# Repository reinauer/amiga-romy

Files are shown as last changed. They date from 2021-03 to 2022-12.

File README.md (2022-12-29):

# Amiga Romy

ROMY is a small add-on PCB that enables Amiga 3000 / 4000 computers to use 1MB (or larger) Kickstart chips.

This project aims at iterating and improving the existing Romy designs.

# Software

Look in the [`software`](software/) directory for a bunch of scripts to create a nice 1MB ROM
image for you.

There's also a small program to create parametrized PLCC plug footprints for
KiCAD.

# Logic

The [`logic`](logic/) directory contains the contents for the GAL 22V10. If you want to
build a ROMY yourself, you will need to program this before soldering your GAL
down.

# Hardware

In the [`hardware`](hardware/) directory you will find the kicad schematics and PCB for the
latest versions of ROMY:

## Amiga 4000 Romy

This version was the first one I made. It fits snugly on top of a soldered-down
Fat Gary. The GAL is a PLCC-28 ATF22V10C type. This design is the most similar
to the original Romy.

<p float="left">
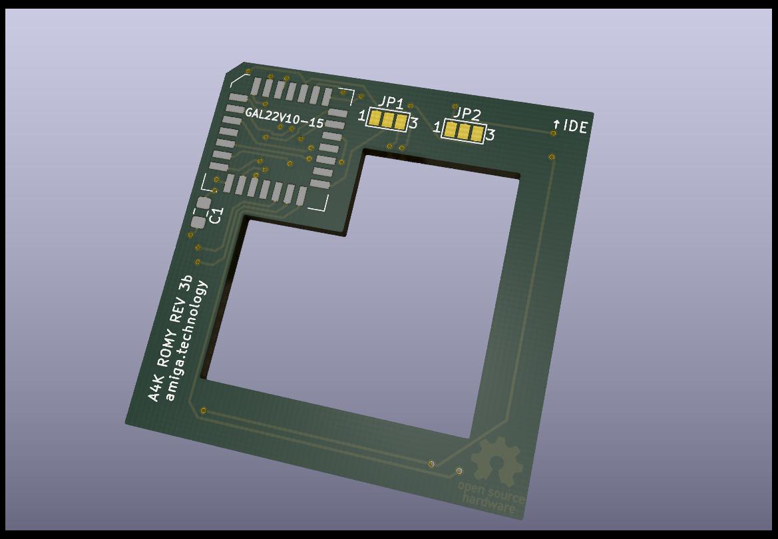
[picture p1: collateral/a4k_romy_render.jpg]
ROMY rendered

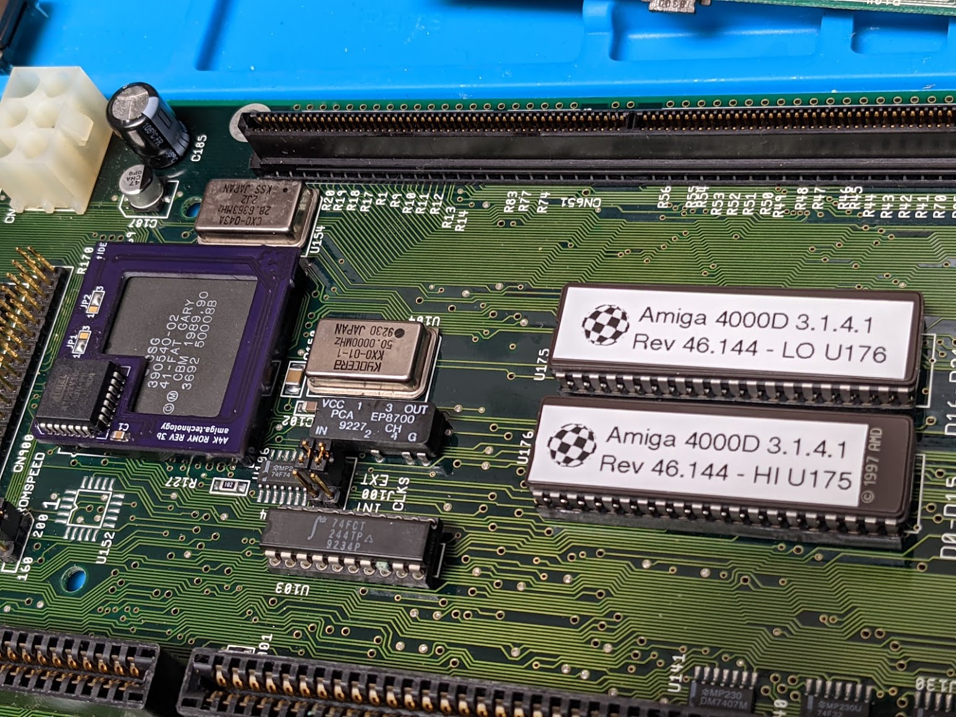
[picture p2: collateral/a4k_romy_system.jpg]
ROMY in the system

</p>

## Amiga 3000 Romy

This version is a revamp of the A3000 Romy. On the A3000 Fat Gary is socketed
using a through-hole PLCC-84 socket. Previous designs have required to unsolder
the socket, and solder a PCB between a socket and the mainboard, in some
variants adding a capacitor on the bottom of the mainboard.

This new design uses a PLCC-28 ATF22V10C GAL instead of the DIP version on
older Amiga 3000 designs. This is convenient because it lets you exchange GALs
between the A3000 and A4000 version.

To prevent having to solder on the A3000 board, I am using PLCC plugs (such as
the APW9328 from adapt-plus.com).

<p float="left">
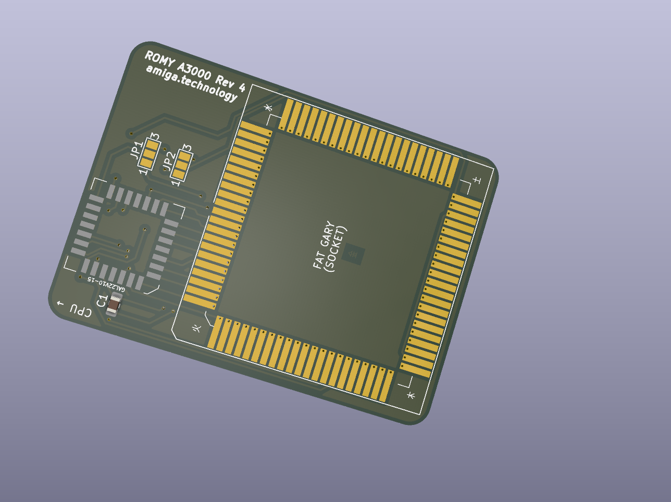
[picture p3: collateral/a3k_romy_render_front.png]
ROMY rendered

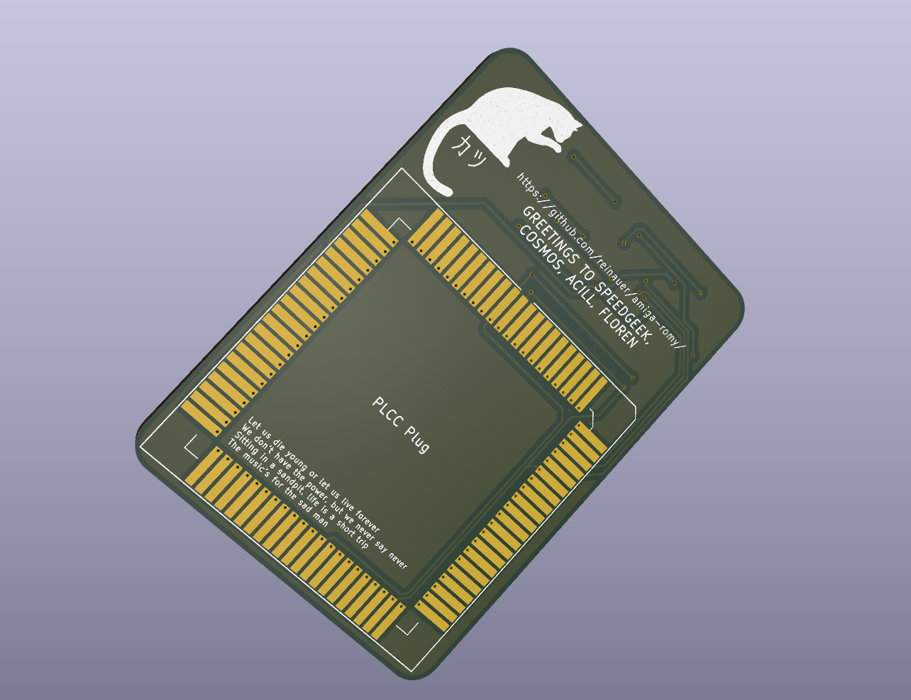
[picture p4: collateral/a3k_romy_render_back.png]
ROMY rendered (back)

</p>

## Ultimate Romy

Now this gets exciting. PLCC parts are annoying to solder and fairly big. So I
skipped DIP and SOIC and went straight to the TSOP version of the ATF22V10C.
The small footprint of this part allows to create a single board for Amiga 3000
and Amiga 4000 machines.

<p float="left">
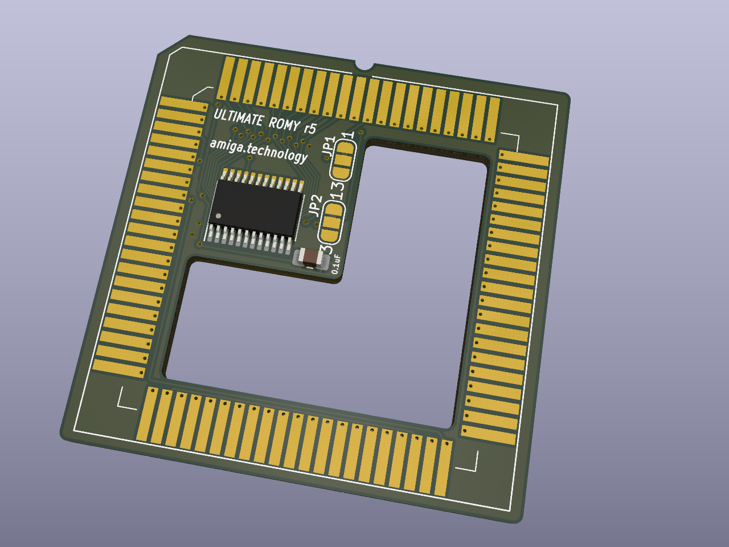
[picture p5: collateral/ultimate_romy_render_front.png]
ROMY rendered

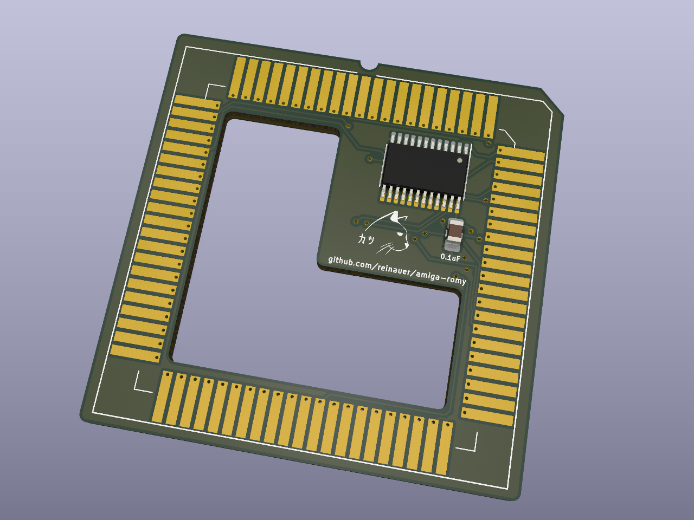
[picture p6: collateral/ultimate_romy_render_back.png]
ROMY rendered (back)

</p>

* If you want to build an A4000 Romy with this design, put a PLCC84 socket on the
back of the PCB, and a capacitor and GAL on the front.
* To build the A3000 version, instead solder a PLCC-84 socket on the front of
the PCB, and solder the cap and GAL on the bottom. Then solder the PLCC plug
over the components.

This design is barely wider than Fat Gary itself and adds the same
functionality as the other ROMYs with minimal impact.

# ROM Extender

<p float="left">
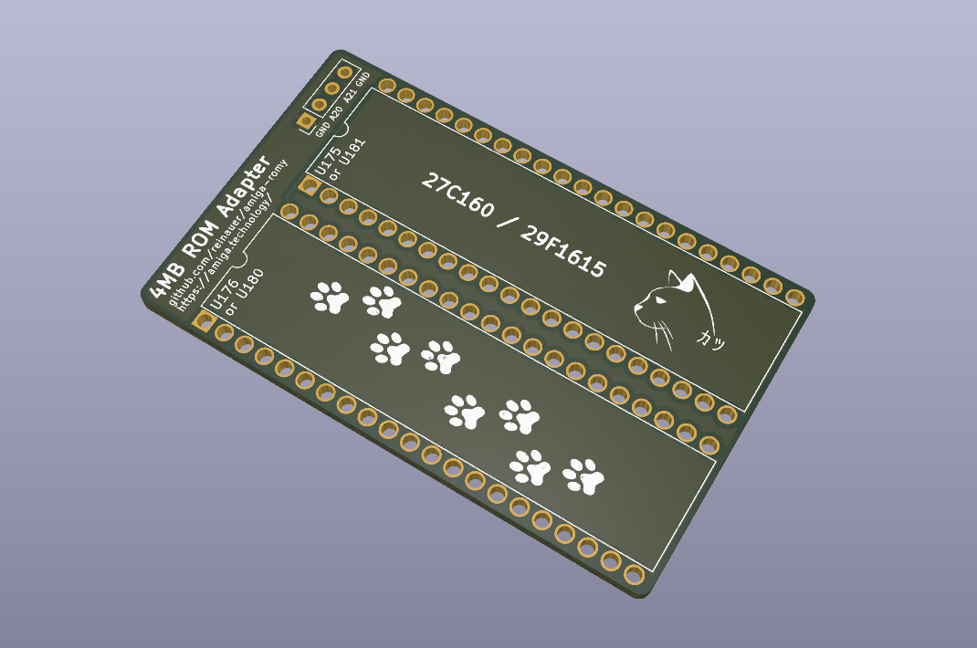
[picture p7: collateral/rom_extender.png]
ROMY 4MB ROM Extender

</p>

The ROM Extender allows the use of 4MB ROM space in an A3000/4000 with the
Ultimate ROMY r6 or newer versions of the A3000 ROMY. You need to connect the
additional address pins between the extender and your ROMY.

When assembling, make sure to optimize for height of the adapter as your
accelerator might have trouble fitting on the A4000.

# Credits

Romy has been developed in the past by speedgeek and Cosmos. Anton Gale kept
the designs alive on OSHPark. Thanks to John Floren for an amazing Amiga 3000,
and to Acill for patiently teaching soldering skills to firmware engineers like
me and for building an awesome community.

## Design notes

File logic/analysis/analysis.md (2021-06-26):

# Prerequisites

* Get OpalJr: wget http://www.brouhaha.com/~eric/retrocomputing/mmi/palasm/opaljr21.zip
* Install galette: https://github.com/simon-frankau/galette

# Get source files

* Use dosbox or dosemu with jed2eqn.
* See script.bat for an automated script

# Conver pin names
* run rename_pins.sh to rename the pins according to the schematics
```
  for f in *.EQN; do
    ./rename_pins.sh $f > ${f%.EQN}.pld
  done
```

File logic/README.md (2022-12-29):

# Logic Files

## Quick Start

The source code and self-compiled files are currently experimental. If you want
a known stable ROMY logic. please refer to the two files

 * RomyRev10.zip
 * RomyRev11.zip

## Overview

The jedec/ directory contains the logic files compiled from the source file in
source/.

There are two different revisions of ROMY:

* Revision 10 is the recommended one for A3000 and A4000D.
* Revision 11 might fix issues with the NCR 710 on A4000T

There are also different versions for 1MB and 4MB ROMYs.

## Building

make will compile all 4 combinations of ROMY logic. You will need
WinCUPL installed under wine.

Help / patches / improvements wanted.

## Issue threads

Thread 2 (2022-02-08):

Cannot make 2mb or 4mb kickstart images

MadMungo, 2022-02-08:
Stephan,

I can successfully make 1MB rom files but as soon as I try to make 2MB or 4MB rom files it errors out with the following

`madmungo@pop-os:~/Amig_Romy$ make kickstart TARGETS="A4000T" SIZES="4mb" VERSION="47.96"
Checking the programs required for the build are installed...
ROMY 1MB/2MB/4MB Kickstart patcher

Fasten your seatbelts and hold your breath (no, better don't!)

Gathering all files... Looking for Hyperion files
  * Can not find /home/madmungo/Downloads/AmigaOS-3.1.4-A3000.zip
  * Can not find /home/madmungo/Downloads/AmigaOS-3.1.4-A4000.zip
  * Can not find /home/madmungo/Downloads/AmigaOS-3.1.4-A4000T.zip
  * Can not find /home/madmungo/Downloads/AmigaOS-3.1.4.1-Update.zip
  * AmigaOS3.2CD.iso cached.
  * Can not find /home/madmungo/Downloads/kick_3.1.4.1.zip
  * Can not find /home/madmungo/Downloads/Update3.2.1.lha
Looking for add-on modules
  * arp40.2.lha cached.
  * vasm.tar.gz cached.
  * rnc_propack_source.zip cached.
  * hrtmon238.lha cached.
  * HRTModule236.lha cached.
  * pfs3aio.lha cached.
  * SFS.lha cached.
Looking for TF1260 drivers
  * ehide.tar.gz cached.
done
 * AmigaOS 3.1.4 A1200 files not found, skipping
 * AmigaOS 3.1.4 A3000 files not found, skipping
 * AmigaOS 3.1.4 A4000 files not found, skipping
 * AmigaOS 3.1.4 A4000T files not found, skipping
 * Unzipping AmigaOS 3.1.4.1 Update ...unzip:  cannot find or open /home/madmungo/Amig_Romy/archives/AmigaOS-3.1.4.1-Update.zip, /home/madmungo/Amig_Romy/archives/AmigaOS-3.1.4.1-Update.zip.zip or /home/madmungo/Amig_Romy/archives/AmigaOS-3.1.4.1-Update.zip.ZIP.
 ok
   * Unpacking * ... ok
 * Unpacking AmigaOS 3.2 ...[sudo] password for madmungo:
Need root access
   * Unpacking diskdoctor ... ok
   * Unpacking install3.2 ... ok
 * Unpacking Arp 40.2 ok
 * Unzipping hrtmodule238 ... ok
 * Unpacking vasm ... ok
 * Unpacking rnc_propack_source ... ok
 * Unpacking PFS3AIO ok
 * Unpacking SmartFileSystem ok
 * Unpacking TF1260 ehide.device ok
Compiling vasm... ok.
Compiling rnc_propack_source... ok.
Compressing hrtmon data... ok.
Compiling HRTmodule 2.38 (16.02.2021)... ok.
Processing Kickstart 47.96 for A4000T (4mb)
Header 11144ef9 512
make: *** [Makefile:31: kickstart] Error 1
`
I also cannot create any other size rom for any other target for any version after successfully  creating a 1MB rom it errors with
make: *** [Makefile:31: kickstart] Error 2. This also happens if I try to make a rom after a reboot of the machine.

reinauer, 2022-02-09:
Yeah, you need to install the latest git revision of amitools. Unfortunately Christian has not released a new version of amitools in the last year or so. that would include my fixes.

MadMungo, 2022-02-09:
Ah OK.

So I am not a linux user, never had to compile stuff before. Are there
instructions on his github page for doing that? & do they include your
fixes?

Phillip

On Wed, 9 Feb 2022, 12:48 pm Stefan Reinauer, ***@***.***>
wrote:

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

reinauer, 2022-02-09:
[According to the author,](https://github.com/cnvogelg/amitools/issues/165) you can install it via
```
pip install -U git+https://github.com/cnvogelg/amitools.git
```

MadMungo, 2022-02-10:
Ok, thanks.

Yes that works for me. Can create all 3 sizes of rom now.

On Thu, 10 Feb 2022, 5:30 am Stefan Reinauer, ***@***.***>
wrote:

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

Closed 2022-02-12.

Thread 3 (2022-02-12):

Cannot make kickstart images for a1200

mikketeus, 2022-02-12:
Hi

I have a TF1260 and would very much like to autoboot from a faster IDE.
I can build A4000 images without any trouble, but not a1200 for some reason?=

make kickstart TARGETS="A1200" VERSION=47.96 SIZES="1mb"
Checking the programs required for the build are installed...
ROMY 1MB/2MB/4MB Kickstart patcher

Fasten your seatbelts and hold your breath (no, better don't!)

Gathering all files... Looking for Hyperion files
  * Can not find /root/Downloads/AmigaOS-3.1.4-A3000.zip
  * Can not find /root/Downloads/AmigaOS-3.1.4-A4000.zip
  * Can not find /root/Downloads/AmigaOS-3.1.4-A4000T.zip
  * Can not find /root/Downloads/AmigaOS-3.1.4.1-Update.zip
  * AmigaOS3.2CD.iso cached.
  * Can not find /root/Downloads/kick_3.1.4.1.zip
  * Can not find /root/Downloads/Update3.2.1.lha
Looking for add-on modules
  * arp40.2.lha cached.
  * vasm.tar.gz cached.
  * rnc_propack_source.zip cached.
  * hrtmon238.lha cached.
  * HRTModule236.lha cached.
  * pfs3aio.lha cached.
  * SFS.lha cached.
Looking for TF1260 drivers
  * ehide.tar.gz cached.
done
 * AmigaOS 3.1.4 A1200 files not found, skipping
 * AmigaOS 3.1.4 A3000 files not found, skipping
 * AmigaOS 3.1.4 A4000 files not found, skipping
 * AmigaOS 3.1.4 A4000T files not found, skipping
 * Unzipping AmigaOS 3.1.4.1 Update ...unzip:  cannot find or open ~/dev/Github/amiga-romy/software/archives/AmigaOS-3.1.4.1-Update.zip,~/dev/Github/amiga-romy/software/archives/AmigaOS-3.1.4.1-Update.zip.zip or ~/dev/Github/amiga-romy/software/archives/AmigaOS-3.1.4.1-Update.zip.ZIP.
 ok
   * Unpacking * ... ok
 * Unpacking AmigaOS 3.2 ...Need root access
   * Unpacking diskdoctor ... ok
   * Unpacking install3.2 ... ok
 * Unpacking Arp 40.2 ok
 * Unzipping hrtmodule238 ... ok
 * Unpacking vasm ... ok
 * Unpacking rnc_propack_source ... ok
 * Unpacking PFS3AIO ok
 * Unpacking SmartFileSystem ok
 * Unpacking TF1260 ehide.device ok
Compiling vasm... ok.
Compiling rnc_propack_source... ok.
Compressing hrtmon data... ok.
Compiling HRTmodule 2.38 (16.02.2021)... ok.
Processing Kickstart 47.96 for A1200 (1mb)
Header 11144ef9 512
make: *** [Makefile:31: kickstart] Error 2

mikketeus, 2022-02-12:
Nevermind, I did some chown's and used my normal user and it worked.

reinauer, 2022-02-12:
Check out this one as well for installing the latest version of amitools
needed for larger rom images and some other features

https://github.com/reinauer/amiga-romy/issues/2#issuecomment-1034068938

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

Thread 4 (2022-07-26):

Assembly error for A1200

JV-Soft, 2022-07-26:
I updated all packages .
Kickstart patch for A4000 and A4000T is made normally only with ROOT, Kickstart patch for A500, A1200, A3000 is an error, it doesn’t matter if there is a ROOT or not

For A4000 -

am@jam-VirtualBox:~/amiga-romy/software$ sudo make kickstart TARGETS="A4000" VERSION=47.102 SIZES="1mb"
Checking the programs required for the build are installed...
ROMY 1MB/2MB/4MB Kickstart patcher

Fasten your seatbelts and hold your breath (no, better don't!)

Processing Kickstart 47.102 for A4000 (1mb)
Header 11144ef9 512
Header 11144ef9 512
Header 11144ef9 512
Success! Now write build/47.102/kick.a4000.47.102.1mb.LO.bin and build/47.102/kick.a4000.47.102.1mb.HI.bin to two 27C400 chips (A4000).

--------------------------------------------------------------------
For A1200 -

jam@jam-VirtualBox:~/amiga-romy/software$ sudo make kickstart TARGETS="A1200" VERSION=47.96 SIZES="1mb"
[sudo] password for jam:
Checking the programs required for the build are installed...
ROMY 1MB/2MB/4MB Kickstart patcher

Fasten your seatbelts and hold your breath (no, better don't!)

Processing Kickstart 47.96 for A1200 (1mb)
Header 11144ef9 512
make: *** [Makefile:31: kickstart] Error 2

------------------------------------------------------------------------------------

After a clean install -

jam@jam-VirtualBox:~/amiga-romy/software$ sudo make kickstart TARGETS="A1200" VERSION=47.96 SIZES="1mb"
Checking the programs required for the build are installed...
ROMY 1MB/2MB/4MB Kickstart patcher

Fasten your seatbelts and hold your breath (no, better don't!)

Gathering all files... Looking for Hyperion files
  * Can not find /root/Downloads/AmigaOS-3.1.4-A3000.zip
  * Can not find /root/Downloads/AmigaOS-3.1.4-A4000.zip
  * Can not find /root/Downloads/AmigaOS-3.1.4-A4000T.zip
  * Can not find /root/Downloads/AmigaOS-3.1.4.1-Update.zip
  * AmigaOS3.2CD.iso cached.
  * Can not find /root/Downloads/kick_3.1.4.1.zip
  * Update3.2.1.lha cached.
Looking for add-on modules
  * arp40.2.lha cached.
  * vasm.tar.gz cached.
  * rnc_propack_source.zip cached.
  * hrtmon238.lha cached.
  * HRTModule236.lha cached.
  * pfs3aio.lha cached.
  * SFS.lha cached.
Looking for TF1260 drivers
  * ehide.tar.gz cached.
done
 * AmigaOS 3.1.4 A1200 files not found, skipping
 * AmigaOS 3.1.4 A3000 files not found, skipping
 * AmigaOS 3.1.4 A4000 files not found, skipping
 * AmigaOS 3.1.4 A4000T files not found, skipping
 * Unzipping AmigaOS 3.1.4.1 Update ...unzip:  cannot find or open /home/jam/amiga-romy/software/archives/AmigaOS-3.1.4.1-Update.zip, /home/jam/amiga-romy/software/archives/AmigaOS-3.1.4.1-Update.zip.zip or /home/jam/amiga-romy/software/archives/AmigaOS-3.1.4.1-Update.zip.ZIP.
 ok
   * Unpacking * ... ok
 * Unpacking AmigaOS 3.2 ...Need root access
   * Unpacking diskdoctor ... ok
   * Unpacking install3.2 ... ok
 * Unpacking AmigaOS 3.2.1 Update ... ok
   * Unpacking DiskDoctor ... ok
   * Unpacking Update3.2.1 ... ok
 * Unpacking Arp 40.2 ok
 * Unzipping hrtmodule238 ... ok
 * Unpacking vasm ... ok
 * Unpacking rnc_propack_source ... ok
 * Unpacking PFS3AIO ok
 * Unpacking SmartFileSystem ok
 * Unpacking TF1260 ehide.device ok
Compiling vasm... cached.
Compiling rnc_propack_source... cached.
Compressing hrtmon data... cached.
Compiling HRTmodule 2.38 (16.02.2021)... cached.
Processing Kickstart 47.96 for A1200 (1mb)
Header 11144ef9 512
make: *** [Makefile:31: kickstart] Error 2

JV-Soft, 2022-07-26:
I also wanted to say that after the error, only one file is created in the build / 47.96 folder, this is kick.a1200.47.96-512kb
I checked it, it's a working kickstart 47.96

JV-Soft, 2022-07-26:
Updated amitools as you recommended, did not help

jam@jam-VirtualBox:~/amiga-romy/software$ make kickstart TARGETS="A1200" VERSION=47.96 SIZES="1mb"
Checking the programs required for the build are installed...
ROMY 1MB/2MB/4MB Kickstart patcher

Fasten your seatbelts and hold your breath (no, better don't!)

Processing Kickstart 47.96 for A1200 (1mb)
2022-07-26 23:44:18,628  ERROR       root        IO Error: [Errno 13] Permission denied: 'ArpLib40.2/arp.library'
make: *** [Makefile:31: kickstart] Error 1

With ROOT rights -

jam@jam-VirtualBox:~/amiga-romy/software$ sudo make kickstart TARGETS="A1200" VERSION=47.96 SIZES="1mb"
[sudo] password for jam:
Checking the programs required for the build are installed...
ROMY 1MB/2MB/4MB Kickstart patcher

Fasten your seatbelts and hold your breath (no, better don't!)

Processing Kickstart 47.96 for A1200 (1mb)
Header 11144ef9 512
make: *** [Makefile:31: kickstart] Error 2

JV-Soft, 2022-07-26:
And again, the A4000 and A4000T are being made, but the rest are not -

jam@jam-VirtualBox:~/amiga-romy/software$ sudo make kickstart TARGETS="A4000" VERSION=47.96 SIZES="1mb"
Checking the programs required for the build are installed...
ROMY 1MB/2MB/4MB Kickstart patcher

Fasten your seatbelts and hold your breath (no, better don't!)

Processing Kickstart 47.96 for A4000 (1mb)
Header 11144ef9 512
Header 11144ef9 512
Header 11144ef9 512
Success! Now write build/47.96/kick.a4000.47.96.1mb.LO.bin and build/47.96/kick.a4000.47.96.1mb.HI.bin to two 27C400 chips (A4000).

jam@jam-VirtualBox:~/amiga-romy/software$ sudo make kickstart TARGETS="A4000T" VERSION=47.96 SIZES="1mb"
Checking the programs required for the build are installed...
ROMY 1MB/2MB/4MB Kickstart patcher

Fasten your seatbelts and hold your breath (no, better don't!)

Processing Kickstart 47.96 for A4000T (1mb)
Header 11144ef9 512
Header 11144ef9 512
Header 11144ef9 512
Success! Now write build/47.96/kick.a4000t.47.96.1mb.LO.bin and build/47.96/kick.a4000t.47.96.1mb.HI.bin to two 27C400 chips (A4000T).

jam@jam-VirtualBox:~/amiga-romy/software$ sudo make kickstart TARGETS="A3000" VERSION=47.96 SIZES="1mb"
Checking the programs required for the build are installed...
ROMY 1MB/2MB/4MB Kickstart patcher

Fasten your seatbelts and hold your breath (no, better don't!)

Processing Kickstart 47.96 for A3000 (1mb)
Header 11144ef9 512
make: *** [Makefile:31: kickstart] Error 2
jam@jam-VirtualBox:~/amiga-romy/software$ sudo make kickstart TARGETS="A500" VERSION=47.96 SIZES="1mb"
Checking the programs required for the build are installed...
ROMY 1MB/2MB/4MB Kickstart patcher

Fasten your seatbelts and hold your breath (no, better don't!)

Processing Kickstart 47.96 for A500 (1mb)
Header 11144ef9 512
make: *** [Makefile:31: kickstart] Error 2
jam@jam-VirtualBox:~/amiga-romy/software$ sudo make kickstart TARGETS="A1200" VERSION=47.96 SIZES="1mb"
Checking the programs required for the build are installed...
ROMY 1MB/2MB/4MB Kickstart patcher

Fasten your seatbelts and hold your breath (no, better don't!)

Processing Kickstart 47.96 for A1200 (1mb)
Header 11144ef9 512
make: *** [Makefile:31: kickstart] Error 2

reinauer, 2022-09-08:
Your first comment has files left over from running as root. You need to clean them out. The second post is once again using the wrong version of amitools. (probably because the new version is installed for the user but you are running as root again).

JV-Soft, 2022-11-16:
Thank you very much for your work and support!

ср, 16 нояб. 2022 г. в 06:34, Stefan Reinauer ***@***.***>:

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

Closed 2022-11-16.

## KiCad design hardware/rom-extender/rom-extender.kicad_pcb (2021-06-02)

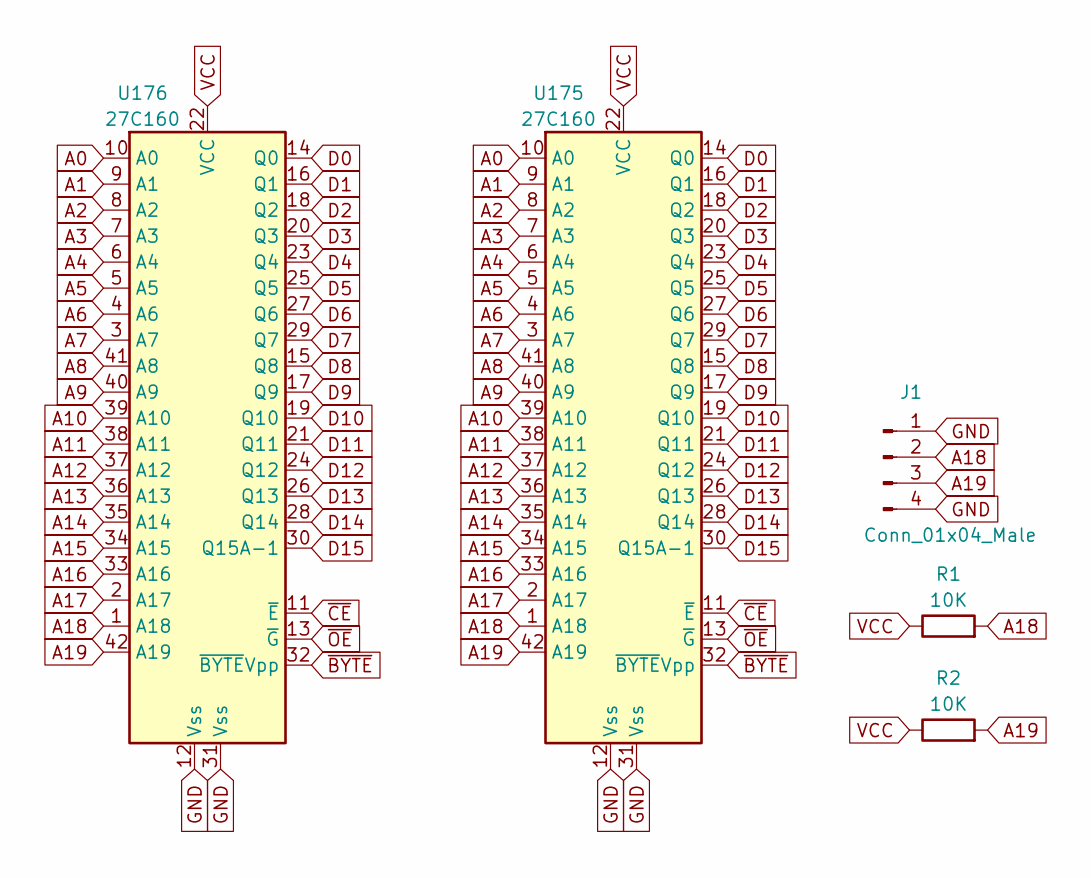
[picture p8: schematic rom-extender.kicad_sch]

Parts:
J1: Conn_01x04_Male; PinHeader_1x04_P2.54mm_Vertical
R1, R2: 10K; R_0805_2012Metric_Pad1.20x1.40mm_HandSolder
U175, U176: 27C160; DIP-42_W15.24mm

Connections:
A0: U175.10 (A0), U176.10 (A0)
A1: U175.9 (A1), U176.9 (A1)
A2: U175.8 (A2), U176.8 (A2)
A3: U175.7 (A3), U176.7 (A3)
A4: U175.6 (A4), U176.6 (A4)
A5: U175.5 (A5), U176.5 (A5)
A6: U175.4 (A6), U176.4 (A6)
A7: U175.3 (A7), U176.3 (A7)
A8: U175.41 (A8), U176.41 (A8)
A9: U175.40 (A9), U176.40 (A9)
A10: U175.39 (A10), U176.39 (A10)
A11: U175.38 (A11), U176.38 (A11)
A12: U175.37 (A12), U176.37 (A12)
A13: U175.36 (A13), U176.36 (A13)
A14: U175.35 (A14), U176.35 (A14)
A15: U175.34 (A15), U176.34 (A15)
A16: U175.33 (A16), U176.33 (A16)
A17: U175.2 (A17), U176.2 (A17)
A18: J1.2, R1.2, U175.1 (A18), U176.1 (A18)
A19: J1.3, R2.2, U175.42 (A19), U176.42 (A19)
D0: U175.14 (Q0), U176.14 (Q0)
D1: U175.16 (Q1), U176.16 (Q1)
D2: U175.18 (Q2), U176.18 (Q2)
D3: U175.20 (Q3), U176.20 (Q3)
D4: U175.23 (Q4), U176.23 (Q4)
D5: U175.25 (Q5), U176.25 (Q5)
D6: U175.27 (Q6), U176.27 (Q6)
D7: U175.29 (Q7), U176.29 (Q7)
D8: U175.15 (Q8), U176.15 (Q8)
D9: U175.17 (Q9), U176.17 (Q9)
D10: U175.19 (Q10), U176.19 (Q10)
D11: U175.21 (Q11), U176.21 (Q11)
D12: U175.24 (Q12), U176.24 (Q12)
D13: U175.26 (Q13), U176.26 (Q13)
D14: U175.28 (Q14), U176.28 (Q14)
D15: U175.30 (Q15A-1), U176.30 (Q15A-1)
GND: J1.1, J1.4, U175.12 (Vss), U175.31 (Vss), U176.12 (Vss), U176.31 (Vss)
VCC: R1.1, R2.1, U175.22 (VCC), U176.22 (VCC)
~BYTE: U175.32 (~BYTE~Vpp), U176.32 (~BYTE~Vpp)
~CE: U175.11 (~E), U176.11 (~E)
~OE: U175.13 (~G), U176.13 (~G)

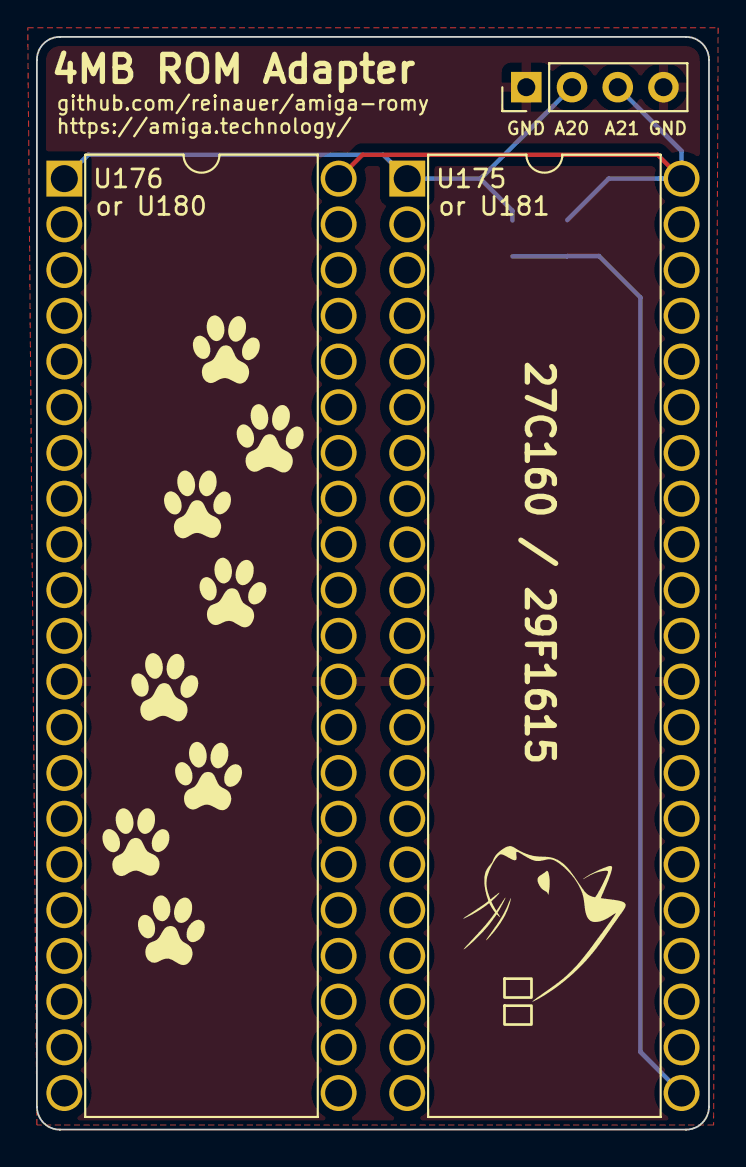
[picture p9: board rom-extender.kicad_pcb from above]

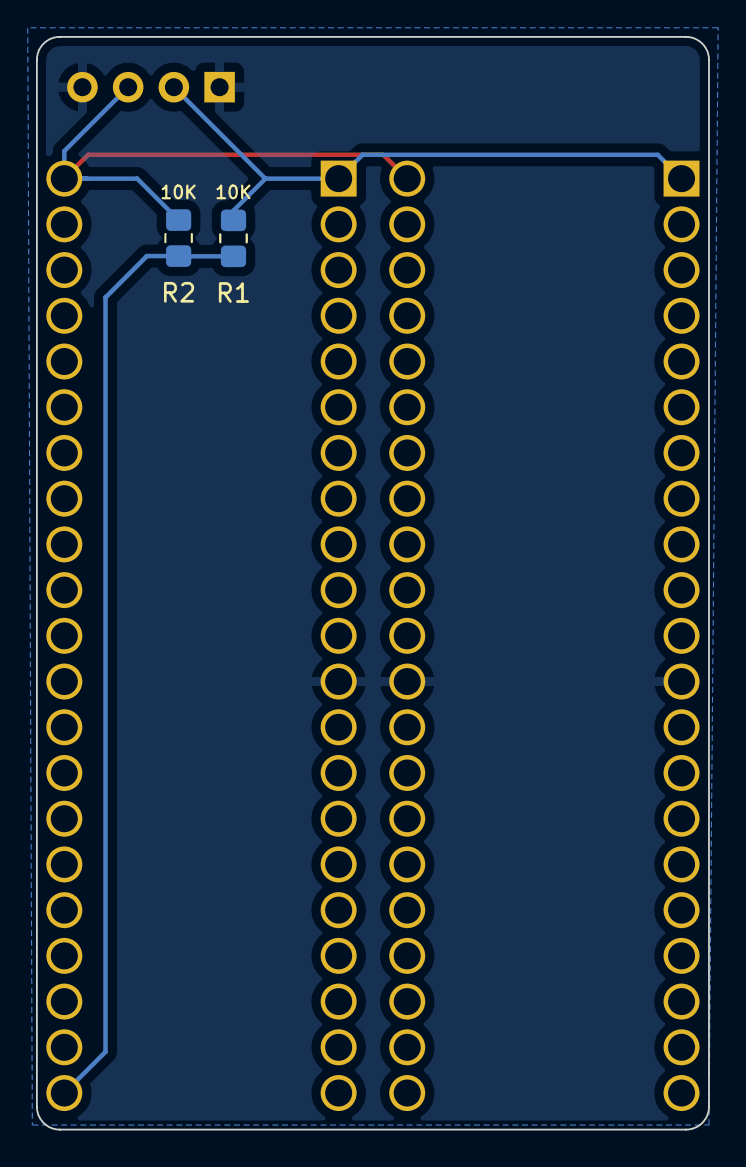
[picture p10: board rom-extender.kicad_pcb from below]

Board: 2 copper layers, 37.3 x 60.7 mm, 5 parts (2 on the bottom side), 41 nets.

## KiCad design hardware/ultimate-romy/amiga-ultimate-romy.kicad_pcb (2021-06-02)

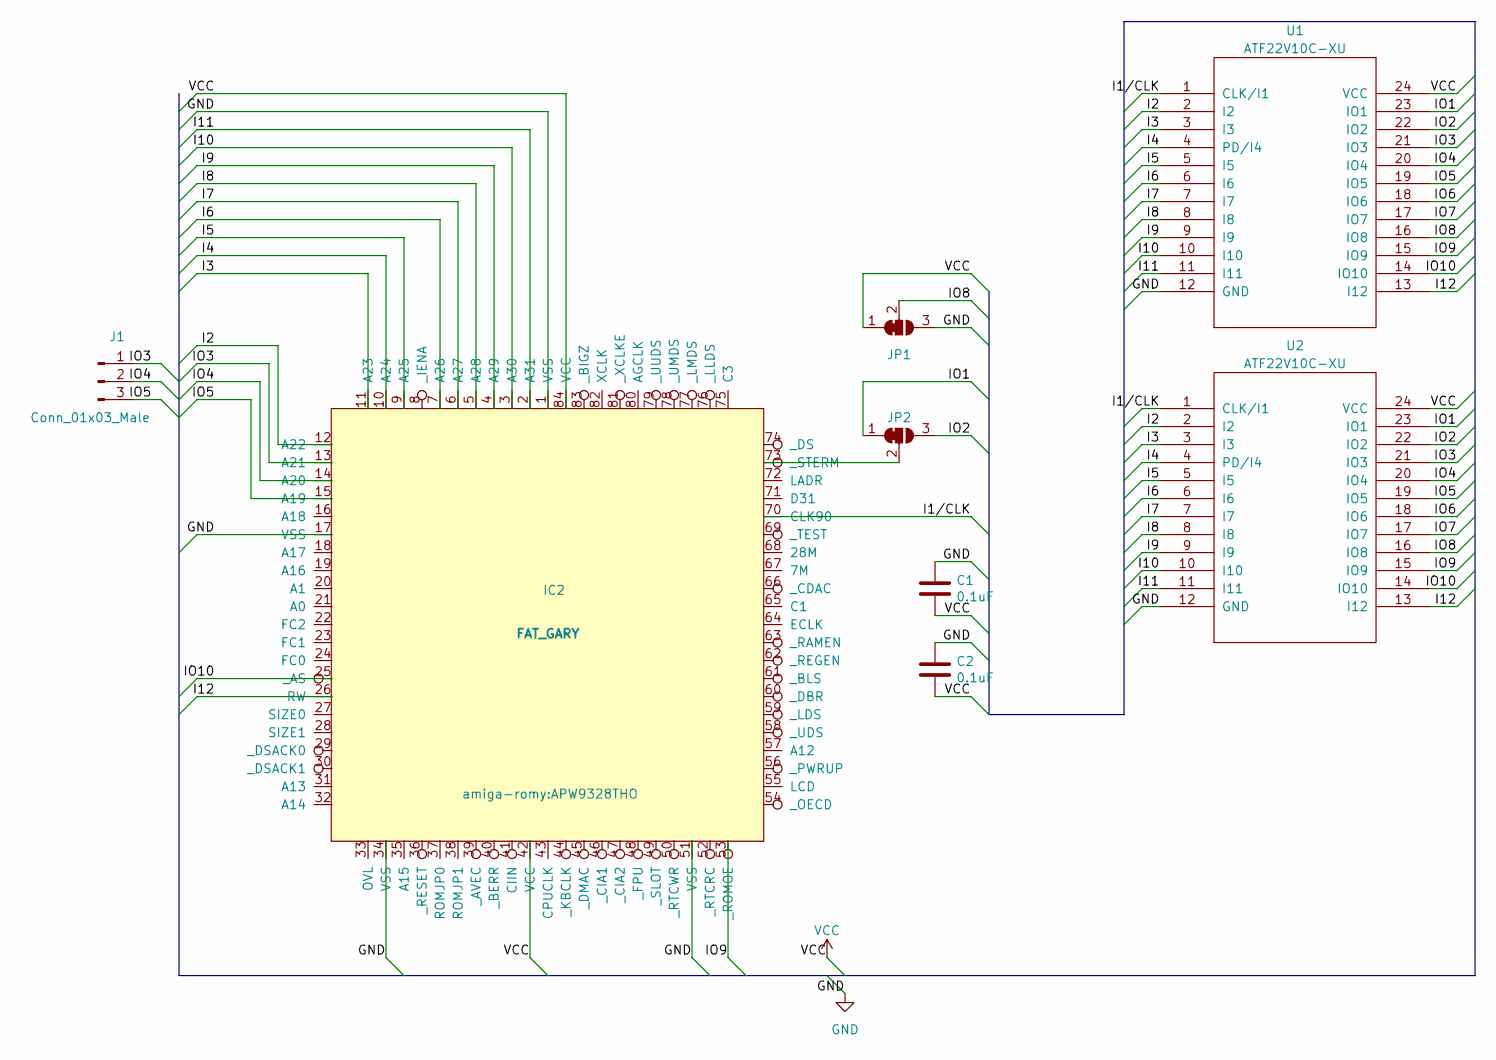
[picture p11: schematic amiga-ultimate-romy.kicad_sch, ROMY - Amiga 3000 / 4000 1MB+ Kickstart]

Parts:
C1, C2: 0.1uF; C_0805_2012Metric_Pad1.18x1.45mm_HandSolder
IC2: FAT_GARY; APW9328THO
J1: Conn_01x03_Male; PinHeader_1x03_P2.54mm_Vertical
JP1, JP2: SolderJumper_3_Bridged12; SolderJumper-3_P1.3mm_Bridged12_RoundedPad1.0x1.5mm_NumberL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
U1, U2: ATF22V10C-XU; asym_TSSOP-24_4.4x7.8mm_P0.65mm

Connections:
/I1/CLK: IC2.70 (CLK90), U1.1 (CLK/I1), U2.1 (CLK/I1)
/I2: IC2.12 (A22), U1.2 (I2), U2.2 (I2)
/I3: IC2.11 (A23), U1.3 (I3), U2.3 (I3)
/I4: IC2.10 (A24), U1.4 (PD/I4), U2.4 (PD/I4)
/I5: IC2.9 (A25), U1.5 (I5), U2.5 (I5)
/I6: IC2.7 (A26), U1.6 (I6), U2.6 (I6)
/I7: IC2.6 (A27), U1.7 (I7), U2.7 (I7)
/I8: IC2.5 (A28), U1.8 (I8), U2.8 (I8)
/I9: IC2.4 (A29), U1.9 (I9), U2.9 (I9)
/I10: IC2.3 (A30), U1.10 (I10), U2.10 (I10)
/I11: IC2.2 (A31), U1.11 (I11), U2.11 (I11)
/I12: IC2.26 (RW), U1.13 (I12), U2.13 (I12)
/IO1: JP2.1 (A), U1.23 (IO1), U2.23 (IO1)
/IO2: JP2.3 (B), U1.22 (IO2), U2.22 (IO2)
/IO3: IC2.13 (A21), J1.1, U1.21 (IO3), U2.21 (IO3)
/IO4: IC2.14 (A20), J1.2, U1.20 (IO4), U2.20 (IO4)
/IO5: IC2.15 (A19), J1.3, U1.19 (IO5), U2.19 (IO5)
/IO6: U1.18 (IO6), U2.18 (IO6)
/IO7: U1.17 (IO7), U2.17 (IO7)
/IO8: JP1.2 (C), U1.16 (IO8), U2.16 (IO8)
/IO9: IC2.53 (_ROMOE), U1.15 (IO9), U2.15 (IO9)
/IO10: IC2.25 (_AS), U1.14 (IO10), U2.14 (IO10)
GND: C1.1, C2.1, IC2.1 (VSS), IC2.17 (VSS), IC2.34 (VSS), IC2.51 (VSS), JP1.3 (B), U1.12 (GND), U2.12 (GND)
unnamed: IC2.73 (_STERM), JP2.2 (C)
VCC: C1.2, C2.2, IC2.42 (VCC), IC2.84 (VCC), JP1.1 (A), U1.24 (VCC), U2.24 (VCC)

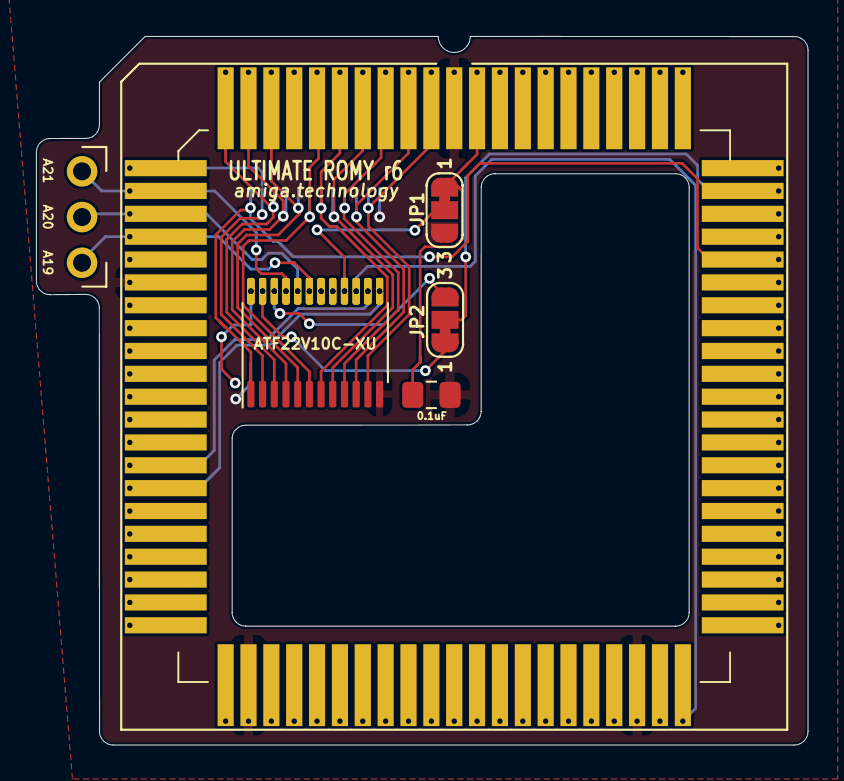
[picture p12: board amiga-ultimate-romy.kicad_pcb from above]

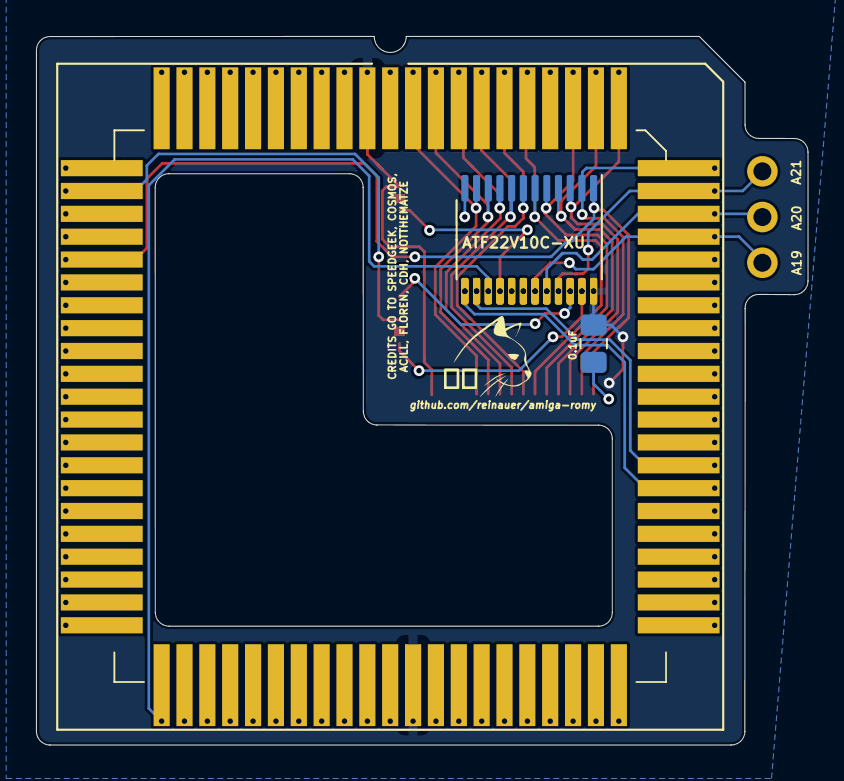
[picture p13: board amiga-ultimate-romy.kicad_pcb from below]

Board: 2 copper layers, 42.9 x 39.4 mm, 9 parts (3 on the bottom side), 25 nets.

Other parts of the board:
カツ: Katsu

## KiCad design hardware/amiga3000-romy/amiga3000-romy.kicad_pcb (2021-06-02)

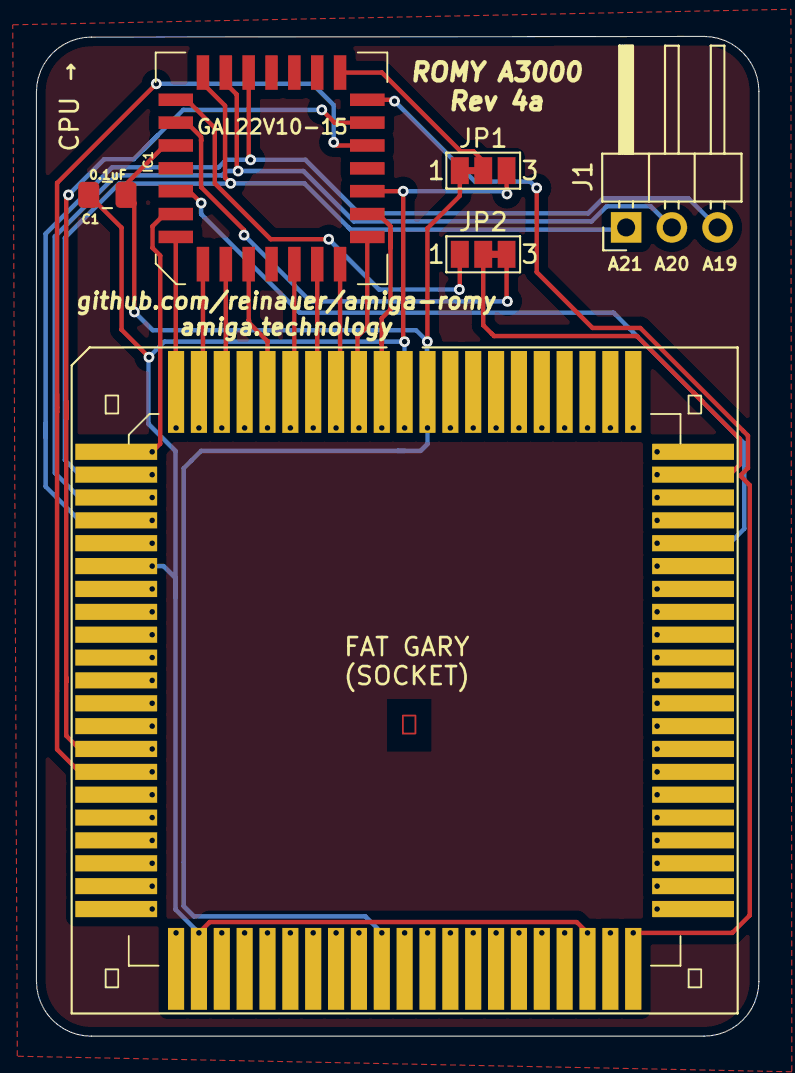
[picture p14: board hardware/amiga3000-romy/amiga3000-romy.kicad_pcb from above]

Board: 2 copper layers, 40.1 x 55.5 mm, 6 parts (1 on the bottom side), 23 nets.

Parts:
C1: 0.1uF; C_0805_2012Metric_Pad1.18x1.45mm_HandSolder
IC1: GAL22V10; PLCC-28
IC2: FAT_GARY; APW9328TH
J1: Conn_01x03_Male; PinHeader_1x03_P2.54mm_Horizontal
JP1: SolderJumper_3_Open; SolderJumper-3_P1.3mm_Closed_12_Pad1.0x1.5mm_NumberLabels
JP2: SolderJumper_3_Open; SolderJumper-3_P1.3mm_Closed_23_Pad1.0x1.5mm_NumberLabels

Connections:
unnamed: C1.1, IC1.14 (GND), IC2.1 (VSS), IC2.17 (VSS), IC2.34 (VSS), IC2.51 (VSS), JP1.3 (B)
unnamed: C1.2, IC1.28 (VCC), IC2.42 (VCC), IC2.84 (VCC), JP1.1 (A)
unnamed: IC1.2 (I1/CLK), IC2.70 (CLK90)
unnamed: IC1.3 (I2), IC2.12 (A22)
unnamed: IC1.4 (I3), IC2.11 (A23)
unnamed: IC1.5 (I4), IC2.10 (A24)
unnamed: IC1.6 (I5), IC2.9 (A25)
unnamed: IC1.7 (I6), IC2.7 (A26)
unnamed: IC1.9 (I7), IC2.6 (A27)
unnamed: IC1.10 (I8), IC2.5 (A28)
unnamed: IC1.11 (I9), IC2.4 (A29)
unnamed: IC1.12 (I10), IC2.3 (A30)
unnamed: IC1.13 (I11), IC2.2 (A31)
unnamed: IC1.16 (I12), IC2.26 (RW)
unnamed: IC1.17 (IO10), IC2.25 (_AS)
unnamed: IC1.18 (IO9), IC2.53 (_ROMOE)
unnamed: IC1.19 (IO8), JP1.2 (C)
unnamed: IC1.23 (IO5), IC2.15 (A19), J1.3
unnamed: IC1.24 (IO4), IC2.14 (A20), J1.2
unnamed: IC1.25 (IO3), IC2.13 (A21), J1.1
unnamed: IC1.26 (IO2), JP2.1 (A)
unnamed: IC1.27 (IO1), JP2.3 (B)
unnamed: IC2.73 (_STERM), JP2.2 (C)

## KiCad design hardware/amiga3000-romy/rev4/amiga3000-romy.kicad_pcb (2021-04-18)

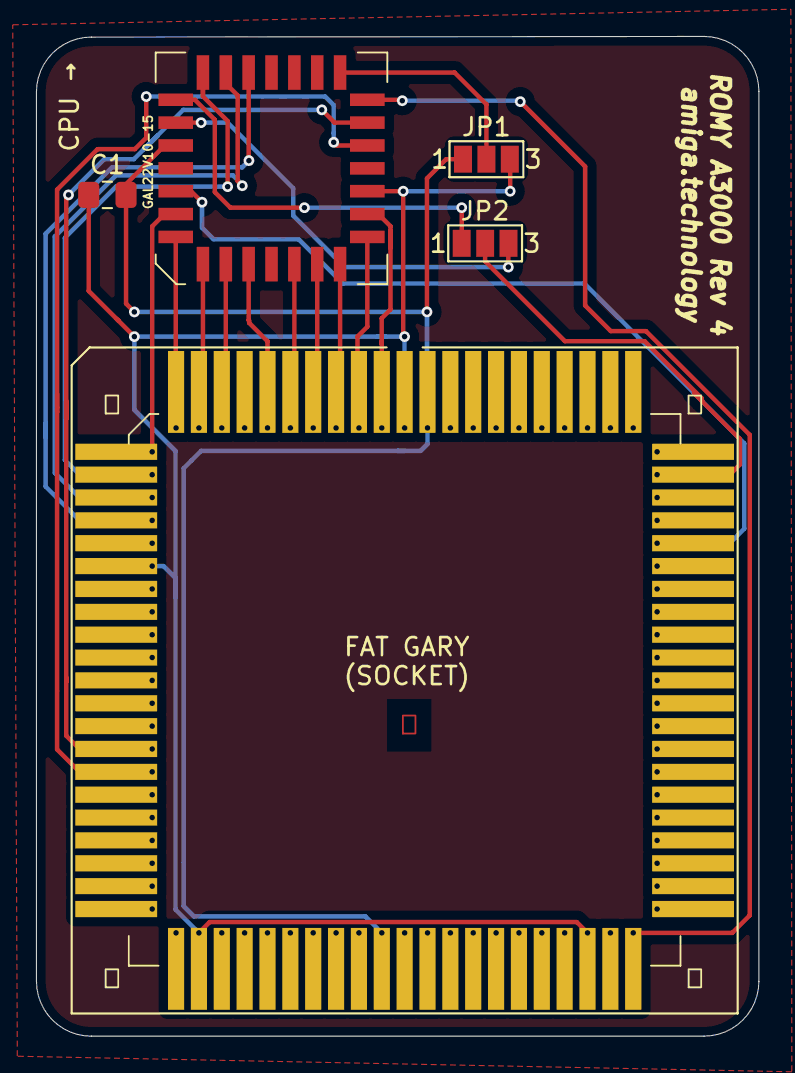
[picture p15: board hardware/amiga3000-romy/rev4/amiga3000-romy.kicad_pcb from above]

Board: 2 copper layers, 40.1 x 55.5 mm, 5 parts (1 on the bottom side), 23 nets.

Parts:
 : FAT_GARY; APW9328TH
C1: 0.1uF; C_0805_2012Metric_Pad1.18x1.45mm_HandSolder
GAL22V10-15: GAL22V10; PLCC-28
JP1, JP2: SolderJumper_3_Open; SolderJumper-3_P1.3mm_Open_Pad1.0x1.5mm_NumberLabels

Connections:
unnamed: .1 (VSS), .17 (VSS), .34 (VSS), .51 (VSS), C1.1, GAL22V10-15.14 (GND), JP1.3 (B)
unnamed: .42 (VCC), .84 (VCC), C1.2, GAL22V10-15.28 (VCC), JP1.1 (A)
unnamed: .70 (CLK90), GAL22V10-15.2 (I1/CLK)
unnamed: .12 (A22), GAL22V10-15.3 (I2)
unnamed: .11 (A23), GAL22V10-15.4 (I3)
unnamed: .10 (A24), GAL22V10-15.5 (I4)
unnamed: .9 (A25), GAL22V10-15.6 (I5)
unnamed: .7 (A26), GAL22V10-15.7 (I6)
unnamed: .6 (A27), GAL22V10-15.9 (I7)
unnamed: .5 (A28), GAL22V10-15.10 (I8)
unnamed: .4 (A29), GAL22V10-15.11 (I9)
unnamed: .3 (A30), GAL22V10-15.12 (I10)
unnamed: .2 (A31), GAL22V10-15.13 (I11)
unnamed: .26 (RW), GAL22V10-15.16 (I12)
unnamed: .25 (_AS), GAL22V10-15.17 (IO10)
unnamed: .53 (_ROMOE), GAL22V10-15.18 (IO9)
unnamed: GAL22V10-15.19 (IO8), JP1.2 (C)
unnamed: .15 (A19), GAL22V10-15.23 (IO5)
unnamed: .14 (A20), GAL22V10-15.24 (IO4)
unnamed: .13 (A21), GAL22V10-15.25 (IO3)
unnamed: GAL22V10-15.26 (IO2), JP2.1 (A)
unnamed: GAL22V10-15.27 (IO1), JP2.3 (B)
unnamed: .73 (_STERM), JP2.2 (C)

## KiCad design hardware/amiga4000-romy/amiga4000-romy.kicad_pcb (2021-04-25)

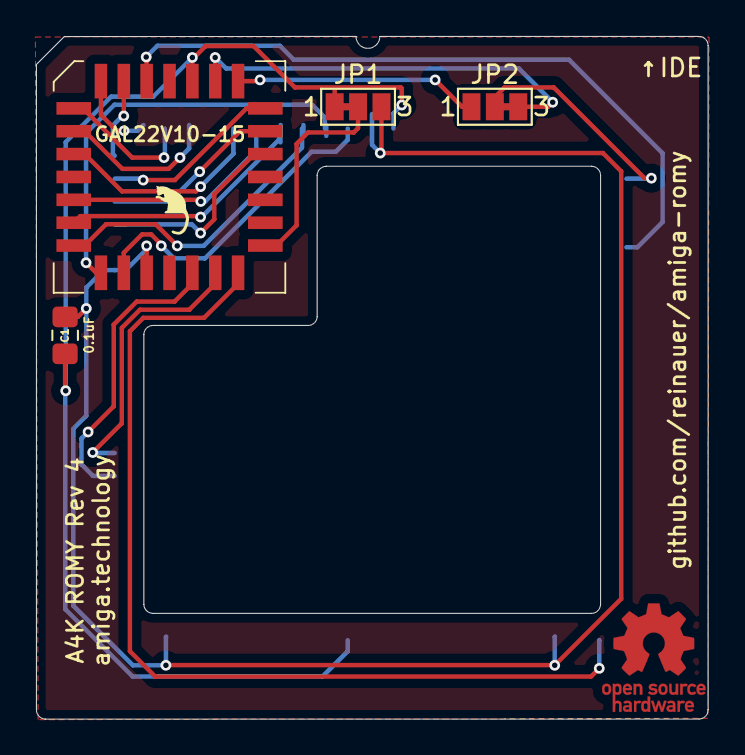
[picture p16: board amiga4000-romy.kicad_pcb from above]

Board: 2 copper layers, 37.3 x 37.9 mm, 5 parts (1 on the bottom side), 23 nets.

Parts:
C1: 0.1uF; C_0805_2012Metric_Pad1.15x1.40mm_HandSolder
FAT GARY: FAT_GARY; PLCC-84_SMD-Socket_mirrored
GAL22V10-15: GAL22V10; PLCC-28
JP1: SolderJumper_3_Open; SolderJumper-3_P1.3mm_Closed_12_Pad1.0x1.5mm_NumberLabels
JP2: SolderJumper_3_Open; SolderJumper-3_P1.3mm_Closed_23_Pad1.0x1.5mm_NumberLabels

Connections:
unnamed: C1.1, FAT GARY.1, FAT GARY.17, FAT GARY.34, FAT GARY.51, GAL22V10-15.14, JP1.3
unnamed: C1.2, FAT GARY.42, FAT GARY.84, GAL22V10-15.28, JP1.1
unnamed: FAT GARY.70, GAL22V10-15.2
unnamed: FAT GARY.12, GAL22V10-15.3
unnamed: FAT GARY.11, GAL22V10-15.4
unnamed: FAT GARY.10, GAL22V10-15.5
unnamed: FAT GARY.9, GAL22V10-15.6
unnamed: FAT GARY.7, GAL22V10-15.7
unnamed: FAT GARY.6, GAL22V10-15.9
unnamed: FAT GARY.5, GAL22V10-15.10
unnamed: FAT GARY.4, GAL22V10-15.11
unnamed: FAT GARY.3, GAL22V10-15.12
unnamed: FAT GARY.2, GAL22V10-15.13
unnamed: FAT GARY.26, GAL22V10-15.16
unnamed: FAT GARY.25, GAL22V10-15.17
unnamed: FAT GARY.53, GAL22V10-15.18
unnamed: GAL22V10-15.19, JP1.2
unnamed: FAT GARY.15, GAL22V10-15.23
unnamed: FAT GARY.14, GAL22V10-15.24
unnamed: FAT GARY.13, GAL22V10-15.25
unnamed: GAL22V10-15.26, JP2.1
unnamed: GAL22V10-15.27, JP2.3
unnamed: FAT GARY.73, JP2.2

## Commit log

2021-03-28 Initial release
    [amiga4000-romy.kicad_pcb, amiga4000-romy.sch]
2021-04-18 Move current version to amiga4000-romy subdirectory
    [amiga4000-romy.kicad_pcb, amiga4000-romy.sch]
2021-04-18 Add footprint generator for PLCC plugs
    I've been using adapt-plus.com's APW9328 PLCC plugs
    for ROMY designs for the machines that have socketed
    PLCC84 chips. Because I suck at Deluxe Paint and other
    graphics tools, I wrote a little program that lets me
    parametrize these PLCC plugs the way I need them.
2021-04-18 Add Amiga 3000 version of the "new" ROMY
    [amiga3000-romy.kicad_pcb, amiga3000-romy.kicad_sch]
2021-04-18 Ultimate ROMY initial version
    [amiga-ultimate-romy.kicad_pcb, amiga-ultimate-romy.kicad_sch]
2021-04-18 Mention PLCC plug footprint generator in documentation
2021-04-25 Minor update to A4000 ROMY
    - rounder edges
    - slightly better routing
    - preset jumpers for two less solder joints
    - move to KiCAD 6.0rc
    [amiga4000-romy.kicad_pcb, amiga4000-romy.kicad_sch, amiga4000-romy.sch]
2021-06-02 Copy Amiga 3000 files to rev4 directory
    [amiga3000-romy.kicad_pcb, amiga3000-romy.kicad_sch]
2021-06-02 Update Amiga3000 ROMY to Rev4a
    major difference is the address header to support 4MB ROMs
    [amiga3000-romy.kicad_pcb, amiga3000-romy.kicad_sch]
2021-06-02 Create copy of Ultimate ROMY rev5
    [amiga-ultimate-romy.kicad_pcb, amiga-ultimate-romy.kicad_sch]
2021-06-02 Update Ultimate ROMY to Rev6
    - Reroute the board to use 6mil instead of 5mil traces.
    This will make the boards significantly cheaper with some fab houses
    - Add address pins for 4MB support
    - Move vias in PLCC footprint to the outside to prevent solder paste
    from leaking to the other side when using hot air to assemble socket
    on A4000 version
    [amiga-ultimate-romy.kicad_pcb, amiga-ultimate-romy.kicad_sch]
2021-06-02 Add 4MB capable ROM extender board
    This board lets you connect two additional pins to newer ROMY revisions
    for 2MB and 4MB ROMs. It can also serve as a simple kickstart switcher
    by itself.
    For Amiga 3000 I recommed http://eebugs.com/amiga/rombankswitcher3000rt/
    Or http://eebugs.com/amiga/rombankswitcher3000/ (version with / without ROM
    tower) made by Chris Hooper.
    [rom-extender.kicad_pcb, rom-extender.kicad_sch]
2021-06-03 Update footprint generator
    - put silkscreen on both sides
    - allow via placement
2021-06-03 Fix ehide.device inclusion
    This will add a warning guru and a long delay to your boot time.
2021-06-26 Make Makefile more useful
    - per default it will print help now
    - allow to specify targets, sizes, and version when calling the
    Makefile
2021-06-27 Update README.md to reflect current software
2021-06-28 Fix ehide.device
2021-06-29 Print the correct(?) chip
    Try to suggest the right chips for programming
2021-07-08 Factor hrtmon, romdisk and ehide.device into modules
2021-07-08 Don't download ehide.device twice
2022-09-08 Make kickstart rom builder work on MacOSX
    This is a pretty big overhaul of the script, that should also benefit
    Linux users:
    - Drop the use of unadf in favor of xdftool which is already installed
    though amitools as we are also using romtool.
    - Don't loopback mount the ISO images but use 7z to extract files. This
    works on non-Linux platforms.
    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
